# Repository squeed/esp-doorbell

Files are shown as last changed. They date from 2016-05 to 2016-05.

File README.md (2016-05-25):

#ESP-Doorbell.

I can't make copies of my apartment building's front door. However, the building
did kindly provide a pair of wires, where connecting one to the other unlocks
the door.

These wires happen to be inside the doorbell, but that's no big deal. The doorbell
has a special chassis for expansion boards!

So, in `/hardware` you'll see a schematic and board design that slots in to the
chassis.

In `/software` you'll find some fun things that will cause various requests to open the door.

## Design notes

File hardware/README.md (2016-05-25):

ESP8266 to Doorbell adapter
===========================

This is a simple PCB that connects an ESP-8266 with a Ritto 6630 door opener. This
sort of hardware is typically used in German apartment buildings. The circuit allows
the front door to be opened via an ESP8266.

This particular telephone has slots for multiple modules within the chassis. This board
is designed to fit in that slot.

The telephone opens the door by tying the Opener signal to Ground. So, this board
provides an optoisolator that simulates pressing the button. The opener signal
is somewhere around 8v, and draws about 12mA when grounded. It needs at least a
transistor for protection, but I'm interfacing via an optocoupler.

Since the system also supplies a 12v power rail, we use that too.

This also exposes the SPI lines to connect an LED strip, because those are useful.
The goal is to someday expose BVG timing on them.

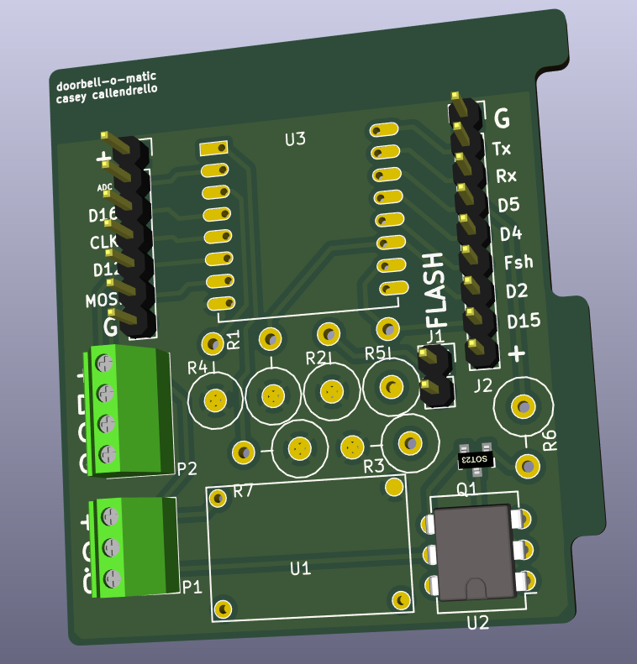
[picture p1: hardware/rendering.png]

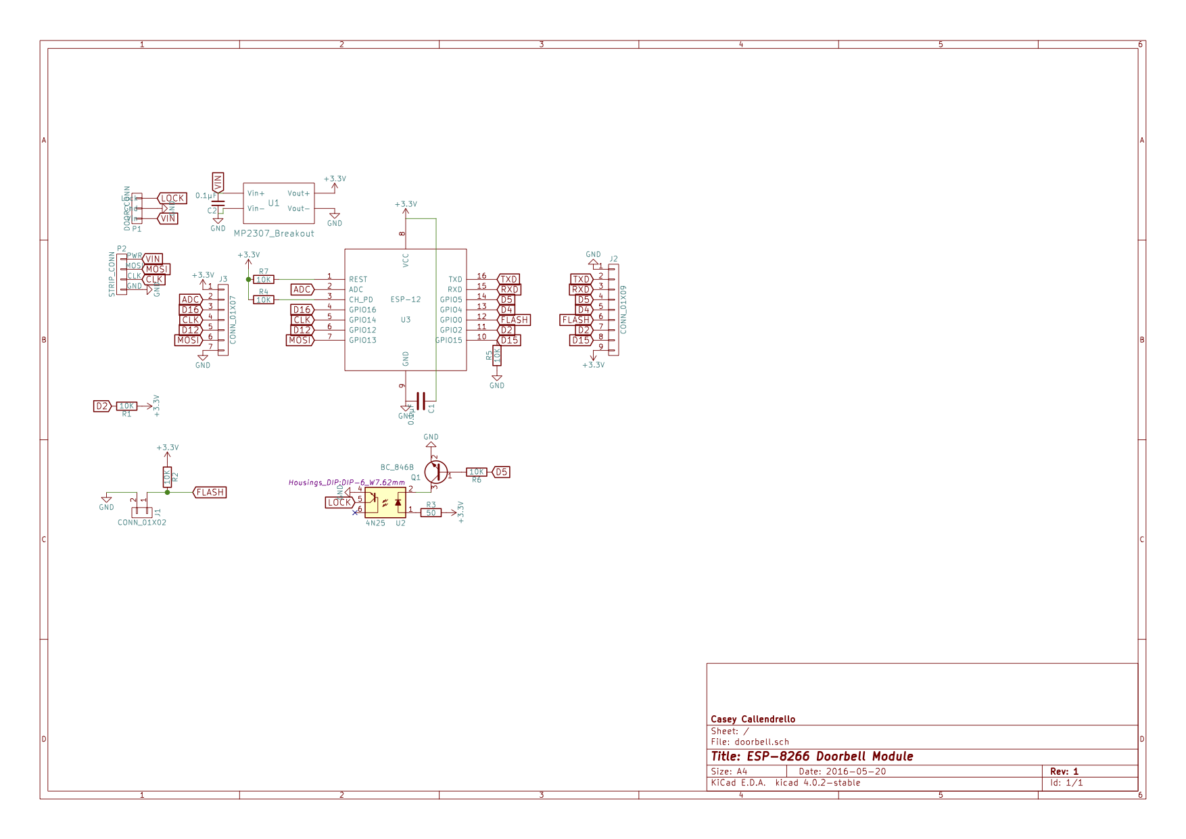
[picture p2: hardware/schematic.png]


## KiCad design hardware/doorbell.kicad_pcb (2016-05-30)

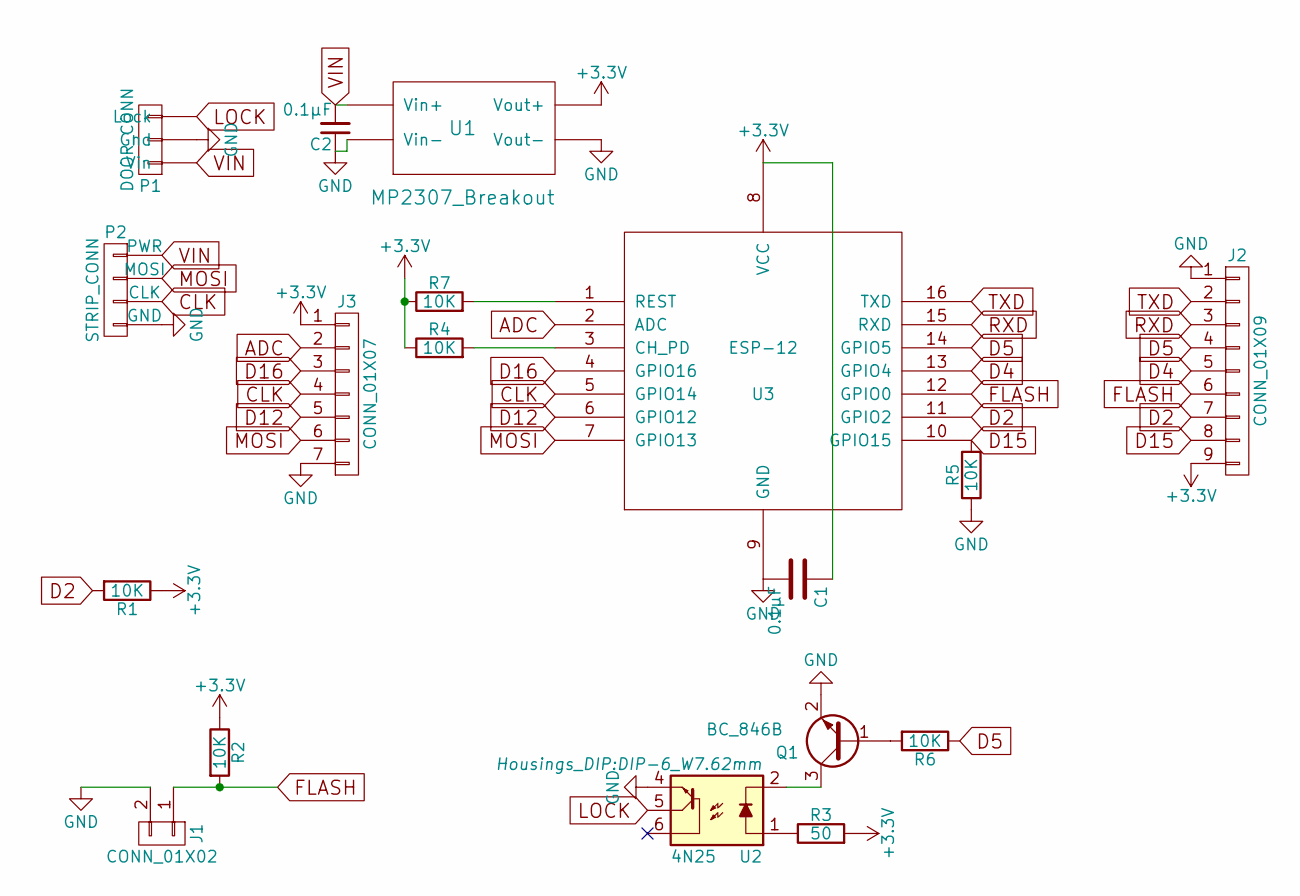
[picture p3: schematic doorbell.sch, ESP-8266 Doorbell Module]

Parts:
C1, C2: 0.1µF; C_1206_HandSoldering
J1: CONN_01X02; Pin_Header_Straight_1x02
J2: CONN_01X09; Pin_Header_Straight_1x09
J3: CONN_01X07; Pin_Header_Straight_1x07
P1: DOOR_CONN; TerminalBlock_Pheonix_MPT-2.54mm_3pol
P2: STRIP_CONN; TerminalBlock_Pheonix_MPT-2.54mm_4pol
Q1: BC_846B; SOT-23_Handsoldering
R1, R2, R4, R5, R6, R7: 10K; Resistor_Vertical_RM5mm
R3: 50; Resistor_Vertical_RM5mm
U1: MP2307_Breakout
U2: 4N25; DIP-6_W7.62mm
U3: ESP-12

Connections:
+3V3: C1.1, J2.9, J3.1, R1.1, R2.1, R3.2, R4.1, R7.1, U1.3 (Vout+), U3.8 (VCC)
ADC: J3.2, U3.2 (ADC)
CLK: J3.4, P2.3 (CLK), U3.5 (GPIO14)
D2: J2.7, R1.2, U3.11 (GPIO2)
D4: J2.5, U3.13 (GPIO4)
D5: J2.4, R6.1, U3.14 (GPIO5)
D12: J3.5, U3.6 (GPIO12)
D15: J2.8, R5.2, U3.10 (GPIO15)
D16: J3.3, U3.4 (GPIO16)
FLASH: J1.1, J2.6, R2.2, U3.12 (GPIO0)
GND: C1.2, C2.1, J1.2, J2.1, J3.7, P1.2 (Gnd), P2.4 (GND), Q1.2 (E), R5.1, U1.2 (Vin-), U1.4 (Vout-), U2.4, U3.9 (GND)
LOCK: P1.3 (Lock), U2.5
MOSI: J3.6, P2.2 (MOSI), U3.7 (GPIO13)
unnamed: Q1.1 (B), R6.2
unnamed: Q1.3 (C), U2.2
unnamed: R3.1, U2.1
unnamed: R4.2, U3.3 (CH_PD)
unnamed: R7.2, U3.1 (REST)
RXD: J2.3, U3.15 (RXD)
TXD: J2.2, U3.16 (TXD)
VIN: C2.2, P1.1 (Vin), P2.1 (PWR), U1.1 (Vin+)

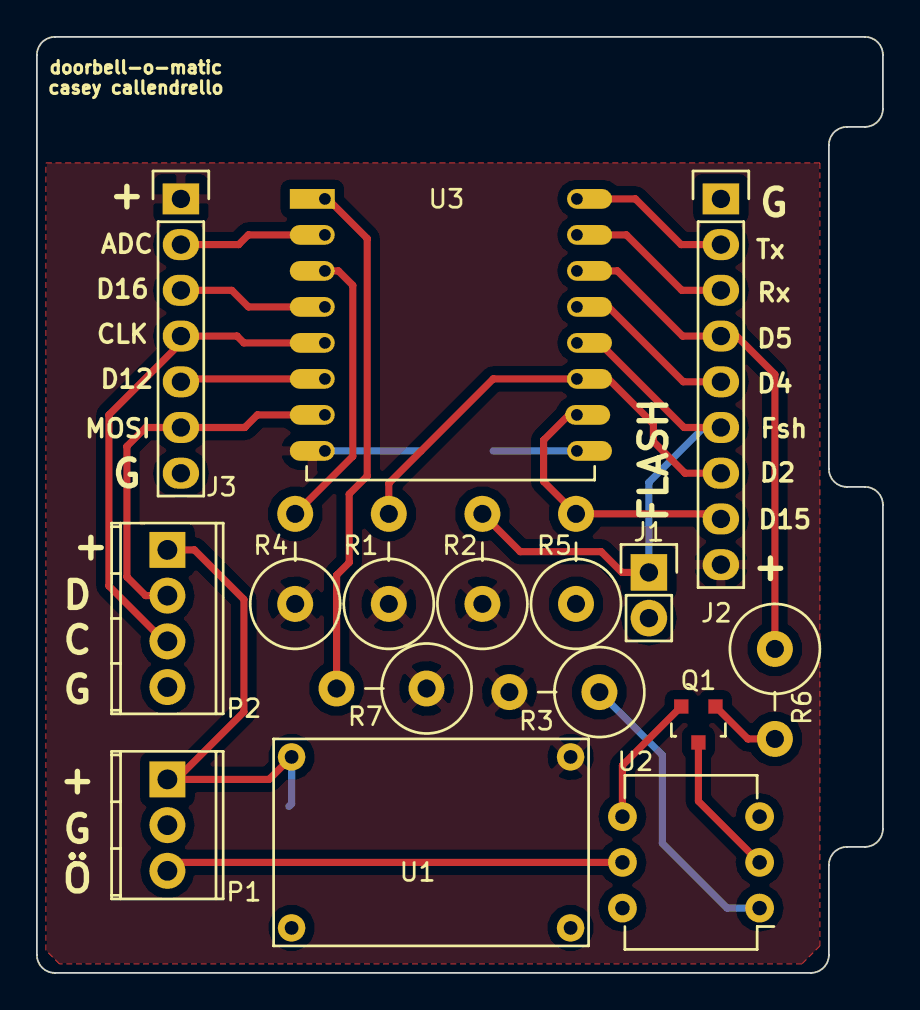
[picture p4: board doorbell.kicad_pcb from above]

Board: 2 copper layers, 47.0 x 52.0 mm, 18 parts (0 on the bottom side), 21 nets.

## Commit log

2016-05-23 My first kicad design ever!
    [doorbell.kicad_pcb, doorbell.sch]
2016-05-23 Add image renders
    [doorbell.sch]
2016-05-24 Fix some library issues
    [doorbell.kicad_pcb, doorbell.sch]
2016-05-24 Fix trace width, expand copper fills
    [doorbell.kicad_pcb]
2016-05-25 Shrink board, expand copper, change Q1 bom
    [doorbell.kicad_pcb, doorbell.sch]
2016-05-30 Convert to include a switching voltage regulator breakout
    [doorbell.kicad_pcb, doorbell.sch]
2016-05-30 Add Vin decoupling cap
    [doorbell.kicad_pcb, doorbell.sch]
2016-05-30 Small text cleanups
    [doorbell.kicad_pcb]
2016-05-30 Final changes. This is the ordered version
    [doorbell.kicad_pcb]
